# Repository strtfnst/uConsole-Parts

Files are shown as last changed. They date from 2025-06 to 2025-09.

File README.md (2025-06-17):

# uConsole printed Parts

Parts are in Beta status. 
After delivery of my uConsole and HG board i will make more adjustments to the files. But delivery will take some time. So i try to make the parts as good as possible. delivery date? -> soon/TBA 

## Remix of uConsole parts:
- front cover with some optical changes
- back cover with cutout for official Raspberry passive cooler (test printing succesful)
- a new version of a stand. Since the original one would not work with back cover 

## Hackergadgets RTL-SDR board cover
A cover to hide and secure the Hackergadgets board
- 2 versions of cover. One with cutout for SD Card access. And one completly covering the top. 
- Power button stl is provided in 2 clearance version. Standard file is with 0,15mm. Optional is with 0,25. Print the one that fits best.

## Screenshots

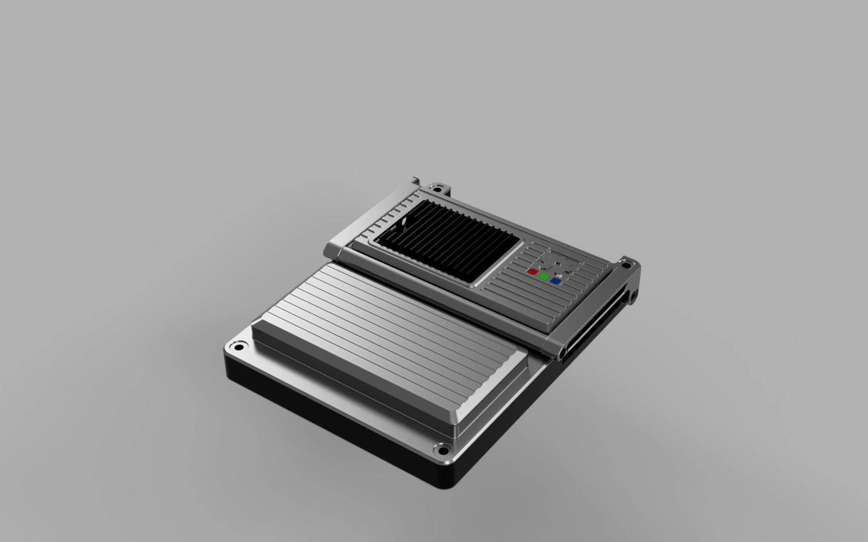
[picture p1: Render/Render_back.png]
Frontrender

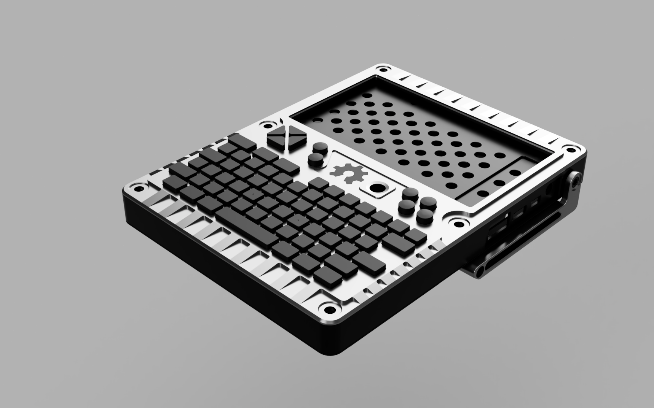
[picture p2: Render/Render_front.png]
Backrender

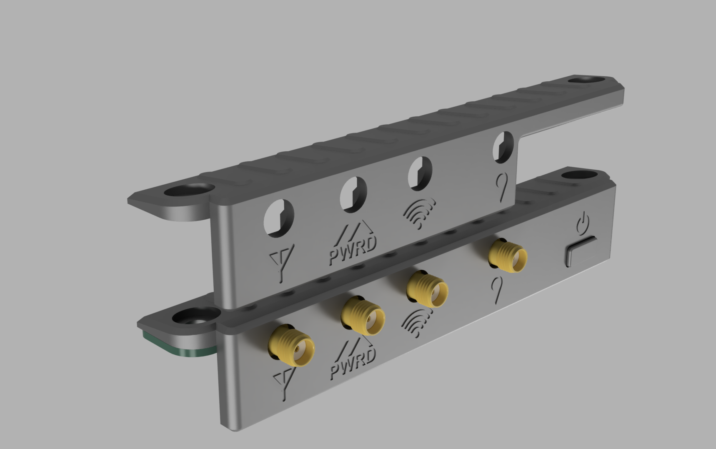
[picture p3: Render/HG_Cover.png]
HG board cover


## Printed and tested. 
Short list of the parts that where succesfuly tested.
- [x] Back cover
- [ ] Front cover
- [ ] Stand
- [X] HG board cover with cutout
- [ ] HG board cover with power button
 
_last updated 17.06.2025_

## Roadmap

- HG cover version for diy SMA connectors.
- back cover version printable with no support. 
- back part with easier access to battery tray.

## BIG thanks

And i would like to thank all the awesome people that helped me so far with this project. 
Printing test parts, providing step files and giving ideas.

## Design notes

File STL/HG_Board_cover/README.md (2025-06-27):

# Hackergaddets Board Cover

## What to print?

### Cover with SD Card access
#### Logo version
- 1x Cover_no_button_logo.stl

#### No Logo version
- 1x Cover_no_button_noLogo.stl

### Cover extendet Version (no quick SD Card access)
#### Logo Version
- 1x Cover_logo.stl
- 1x pwr_button.stl
- optional 1x pwr_button_+25.stl (additional clearance)

#### No Logo Version
- 1x Cover_noLogo.stl
- 1x pwr_button.stl
- optional 1x pwr_button_+25.stl (additional clearance)

#### *optional* SMA connector version
- 1x SMA_Antenna_Cover.stl

## How to print

- Parts need a little support.
- rest of print settings as you like.

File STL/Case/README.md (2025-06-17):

# uConsole printed Parts

## What to print?

### Backcover
- 1x back.stl
- 3x RGB_Insert.stl

### Frontcover
- 1x Front.stl
- 1x Insert.stl

### Stand
- 1x cross_brace.stl
- 1x feet_left.stl
- 1x feet_right.stl

## How to print

- front and back cover need support. Front cover needs tiny amount of support in trackball area. Back the board and battery should be supported.
- rest of print settings as you like.

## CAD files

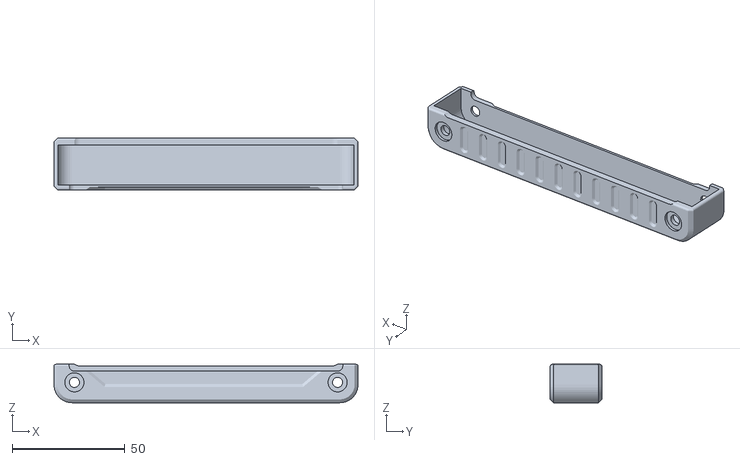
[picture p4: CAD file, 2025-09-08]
STL/Bumper.stl
135.0 x 22.9 x 17.1

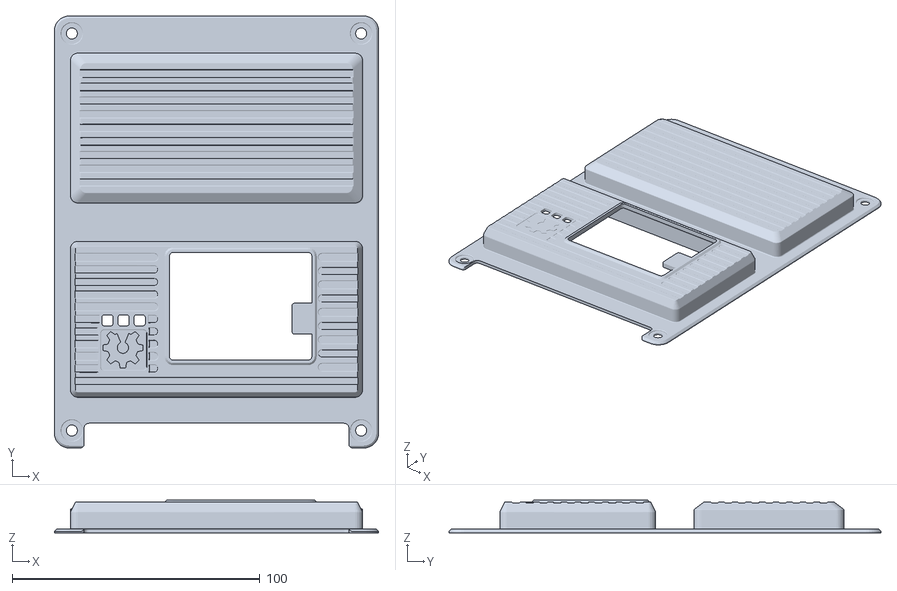
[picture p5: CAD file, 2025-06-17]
STL/Case/Back.stl
131.0 x 174.5 x 13.3

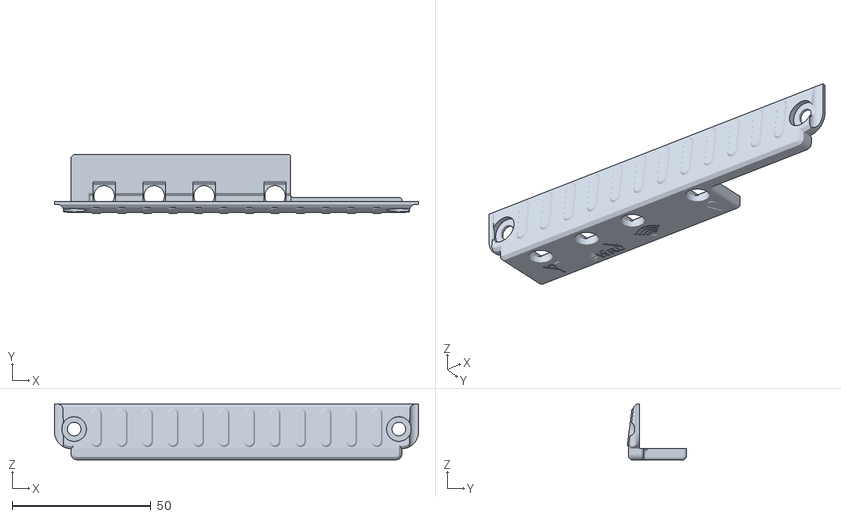
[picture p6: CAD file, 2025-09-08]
STL/HG_Board_cover/Cover_no_button_logo.stl
131.0 x 21.4 x 20.0

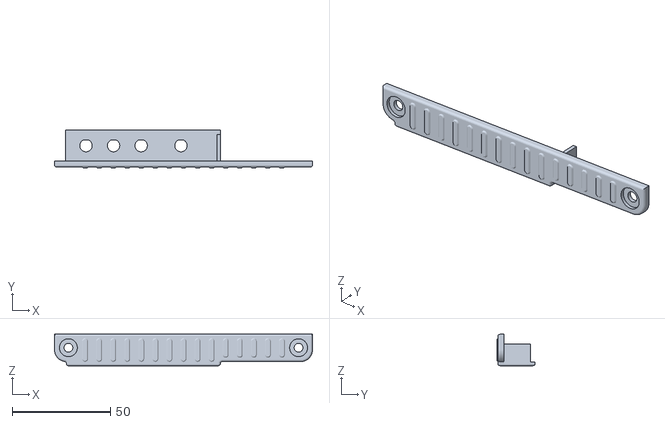
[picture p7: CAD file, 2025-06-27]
STL/HG_Board_cover/optional/SMA_Antenna_Cover.stl
131.0 x 19.3 x 16.0

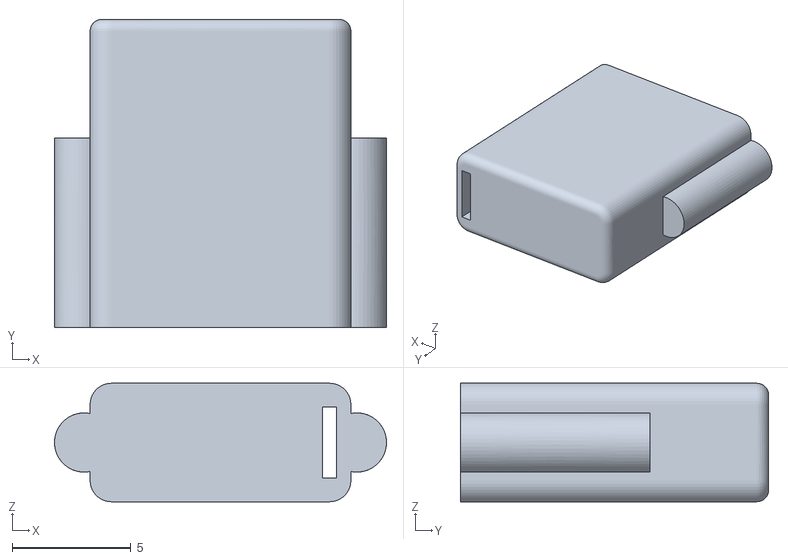
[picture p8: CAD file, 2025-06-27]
STL/HG_Board_cover/Test_files_random/pwr_button_inserts.stl
14.0 x 13.0 x 5.00

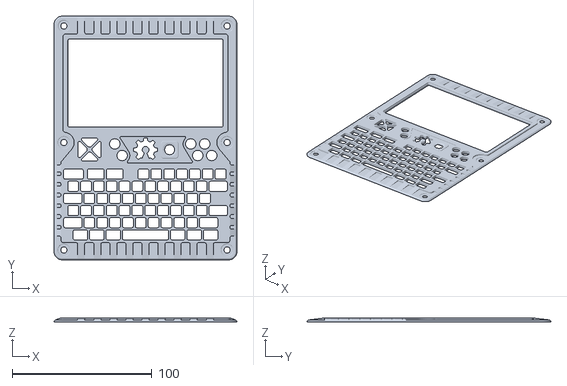
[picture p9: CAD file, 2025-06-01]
STL/Case/Front.stl
131.0 x 174.5 x 2.90

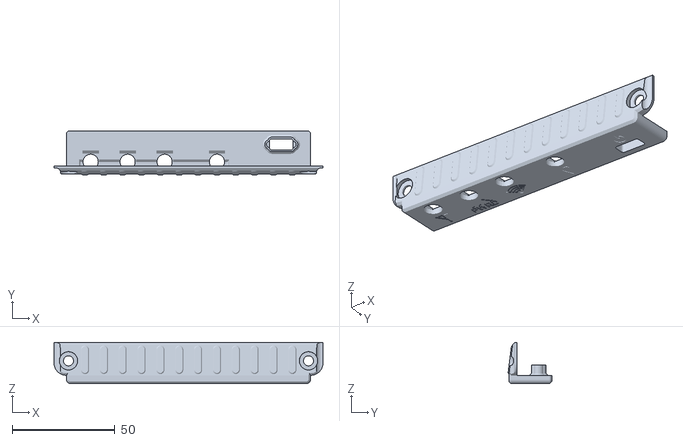
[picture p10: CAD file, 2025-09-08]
STL/HG_Board_cover/Cover_logo.stl
131.0 x 21.4 x 20.0

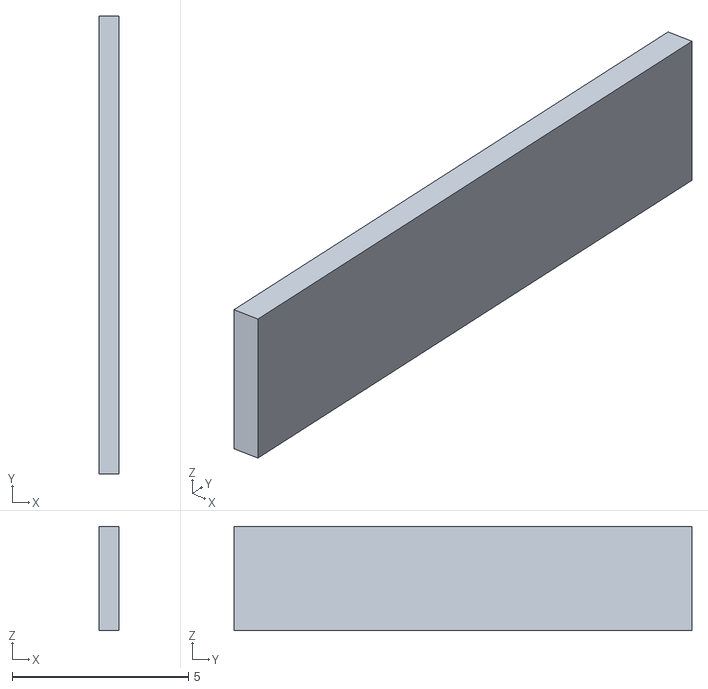
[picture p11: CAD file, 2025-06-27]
STL/HG_Board_cover/Test_files_random/Insert.stl
0.56 x 13.0 x 2.96

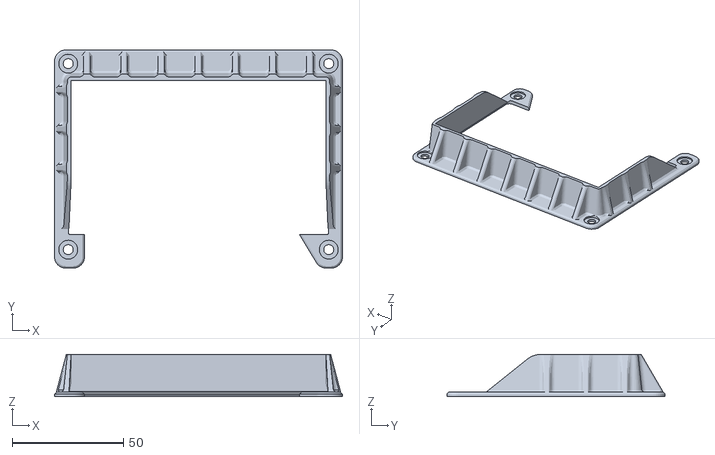
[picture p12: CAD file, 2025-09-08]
STL/Shroud.stl
129.2 x 97.8 x 19.0

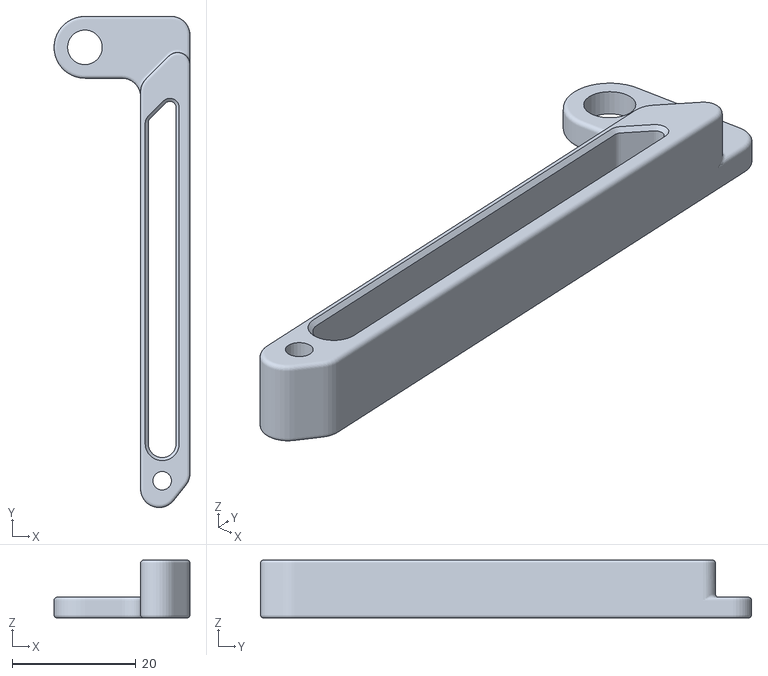
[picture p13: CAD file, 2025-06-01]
STL/Case/feet_right.stl
22.0 x 79.4 x 9.35

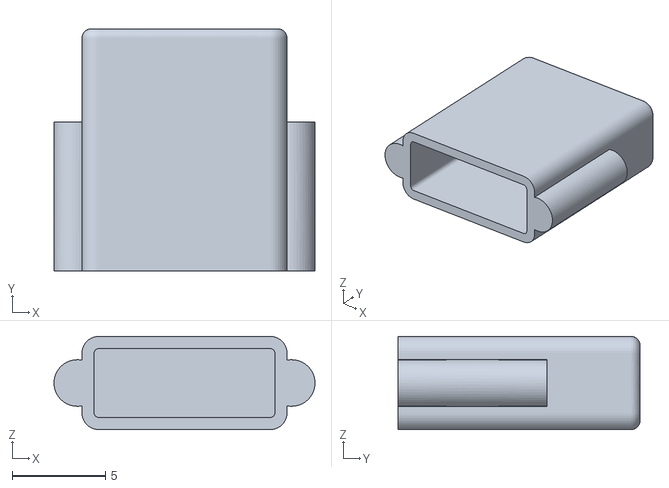
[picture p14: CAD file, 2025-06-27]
STL/HG_Board_cover/Test_files_random/pwr_button_hollow.stl
14.0 x 13.0 x 5.00

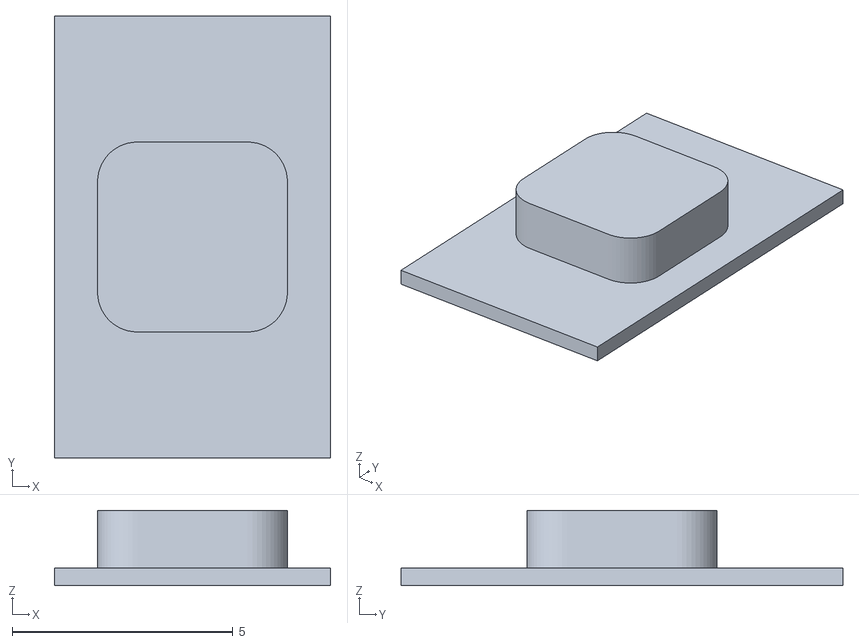
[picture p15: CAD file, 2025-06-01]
STL/Case/3X_RGB_Insert.stl
6.25 x 10.0 x 1.70

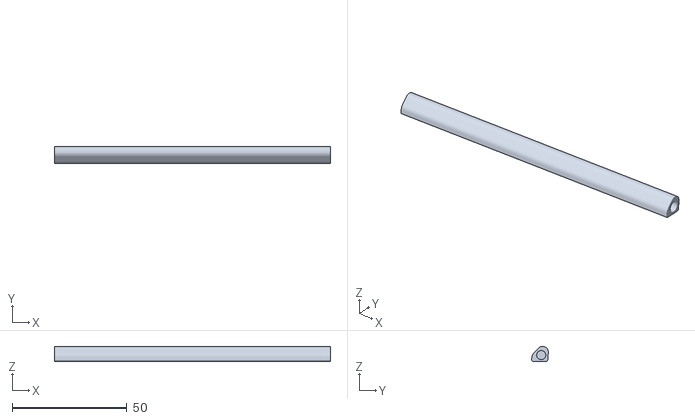
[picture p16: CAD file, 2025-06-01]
STL/Case/Cross_brace.stl
120.1 x 7.29 x 6.59

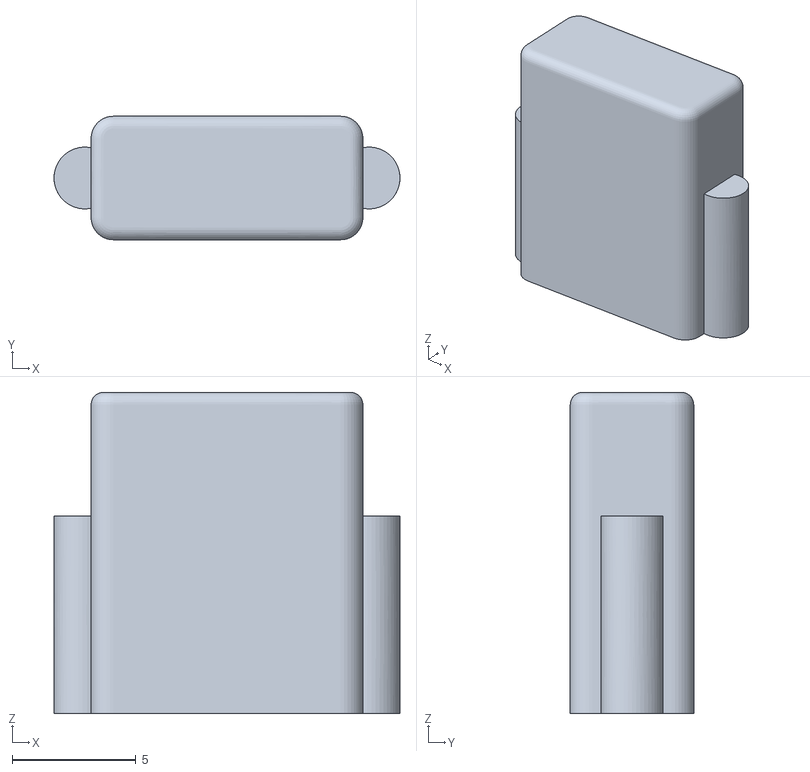
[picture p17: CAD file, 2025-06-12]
STL/HG_Board_cover/pwr_button_+25.stl
14.0 x 5.00 x 13.0

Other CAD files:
STL/HG_Board_cover/STEP Files/HG_cover_noButton_blank.step
STL/HG_Board_cover/STEP Files/HG_cover_blank.step
STL/HG_Board_cover/Cover_noLogo.stl
STL/HG_Board_cover/Cover_no_button_noLogo.stl
STL/Case/Insert.stl
STL/Case/feet_left.stl
STL/HG_Board_cover/pwr_button.stl

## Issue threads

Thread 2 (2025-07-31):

Clearance issues on HG board cover (w/ cutout)

zandr, 2025-07-31:
I just received my HG All-in-one with the antenna board, and printed the board cover (no cutout). There were clearance issues getting the board to fully seat. I was able to adjust the STEP file to make things fit by:

- Increasing the width of the board slot by 1mm in each direction.
- Increasing the relief for the solder side of the SMAs by 1mm towards the uConsole.

I'm not certain that both of these are required, but the board is well located by the mounting screws, so I'm not concerned with tightening things up particularly.

Thank you so much for the design!

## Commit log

2025-06-01 added renders and stl files
    [3X_RGB_Insert.stl, Back.stl, Cross_brace.stl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]
2025-06-09 added stls
    [Cover.stl, pwr_button.stl]
2025-06-09 changed stl orientation
    [Cover.stl, pwr_button.stl]
2025-06-09 Update pwr_button.stl
    wrong inner length of power button
    [pwr_button.stl]
2025-06-10 Update Cover.stl
    - make some clearence adjustments
    - fixed missing extrusion
    [Cover.stl]
2025-06-12 Delete Back.stl
    stl removed. Would not work.
    [Back.stl]
2025-06-12 Create pwr_button_+25.stl
    added power button with more clearance
    [pwr_button_+25.stl]
2025-06-14 updated cover stl
    updated logos on cover stl. Also optional cover with cutout for sd card access.
    [Cover.stl, Cover_no_button.stl]
2025-06-14 readme update and some moving files
    updated readme and moved files around
    [3X_RGB_Insert.stl, Cross_brace.stl, Front.stl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]
2025-06-14 change M logo to M_PWRD
    [Cover.stl, Cover_no_button.stl]
2025-06-14 added step files of covers
    [HG_cover_blank.step, HG_cover_noButton_blank.step]
2025-06-14 added stl version without logos
    [Cover_noLogo.stl, Cover_no_button_noLogo.stl]
2025-06-15 Create Back.stl
    added back.stl back to repo. Testprint was successful
    [Back.stl]
2025-06-15 stl adjustments
    [Cover.stl, Cover_noLogo.stl, Cover_no_button.stl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]
2025-06-16 adjusted clearance
    [HG_cover_blank.step, HG_cover_noButton_blank.step]
2025-06-16 added back logo versions
    [Cover_logo.stl, Cover_no_button_logo.stl]
2025-06-17 orientation fix and more readme
    fixes back.stl orientation.
    Added readme files.
    [Back.stl]
2025-06-27 added Test files
    added variations of power button. Hollow one. And one with transparent insert.
    [Insert.stl, SMA_Antenna_Cover.stl, pwr_button_hollow.stl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]
2025-09-08 updates and more stl
    Made some small adjustments to the cover stl. And also added a shroud and a bottom bumper.
    [Bumper.stl, Cover_logo.stl, Cover_no_button_logo.stl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]
